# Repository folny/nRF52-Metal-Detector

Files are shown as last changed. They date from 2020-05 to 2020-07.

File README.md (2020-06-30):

# nRF52 Metal Detector

Test Video
https://www.youtube.com/watch?v=v60ftfW6UR0

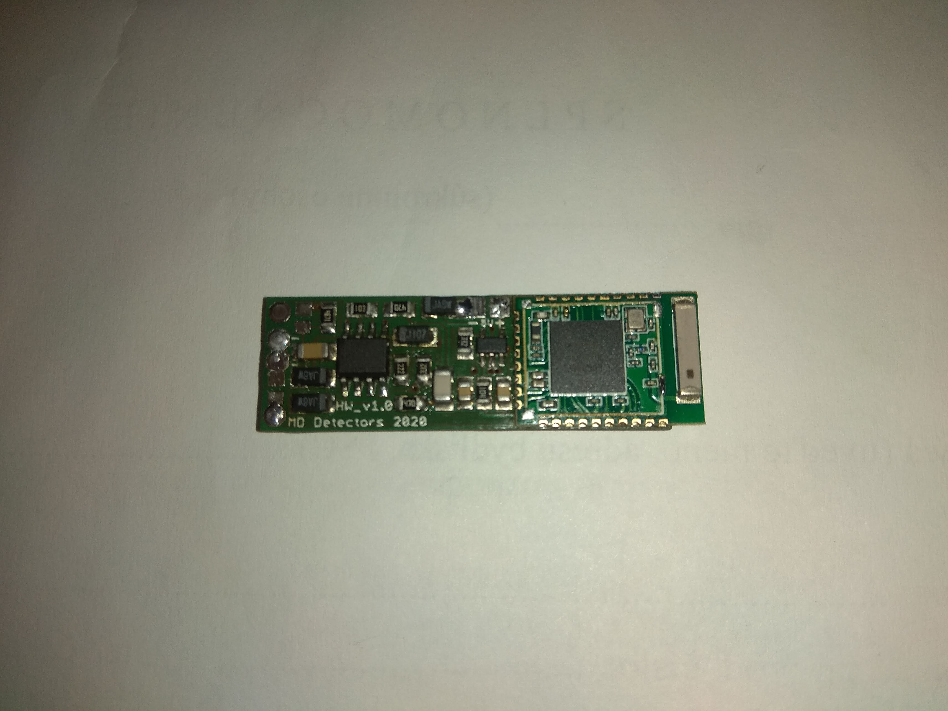
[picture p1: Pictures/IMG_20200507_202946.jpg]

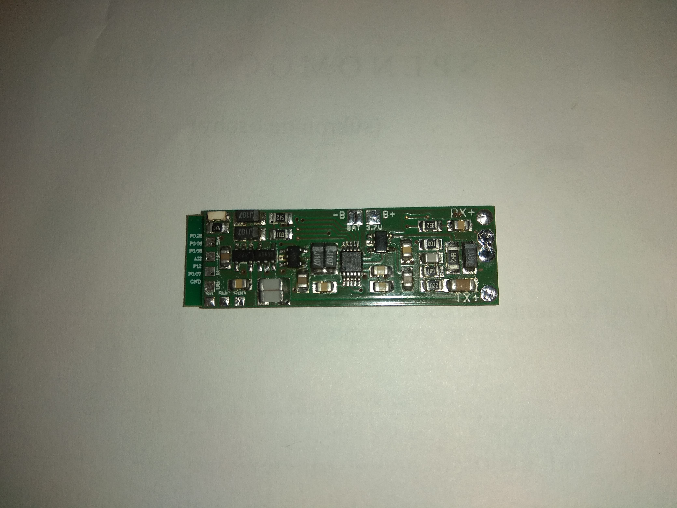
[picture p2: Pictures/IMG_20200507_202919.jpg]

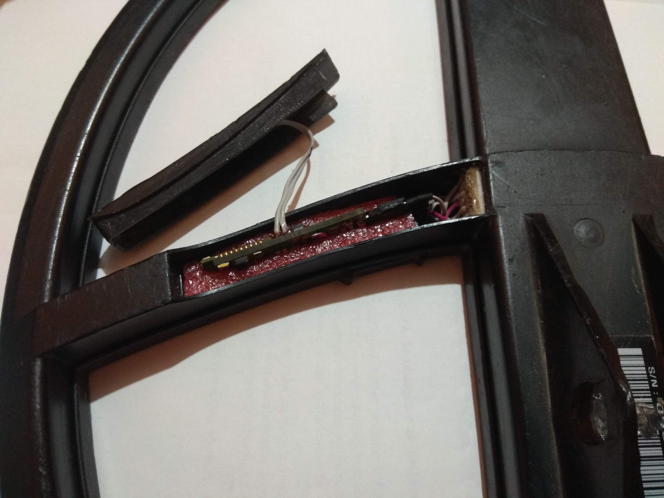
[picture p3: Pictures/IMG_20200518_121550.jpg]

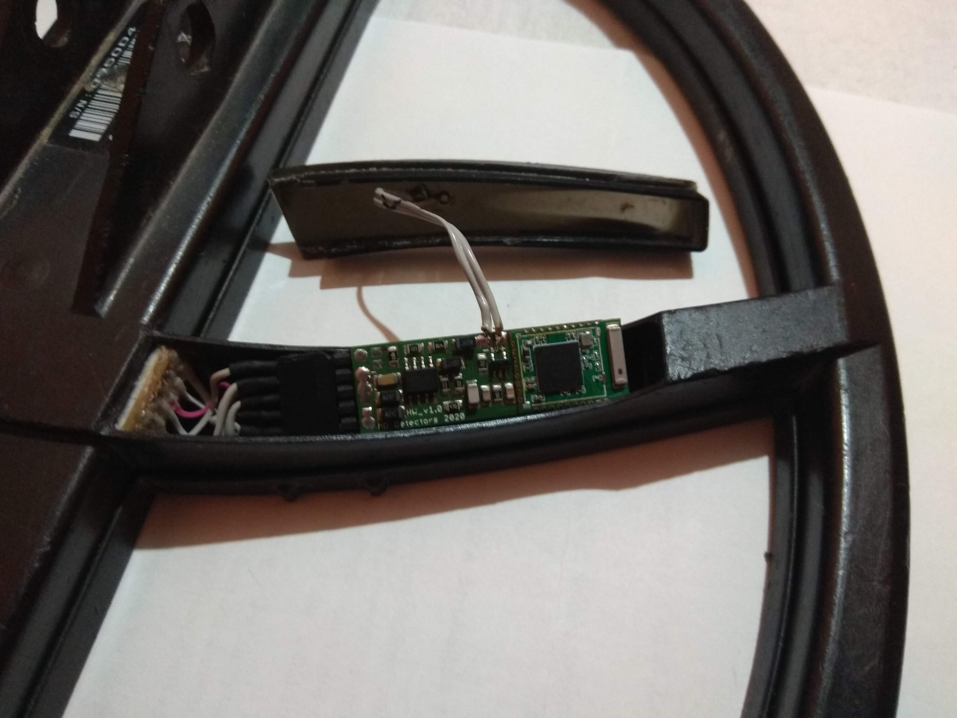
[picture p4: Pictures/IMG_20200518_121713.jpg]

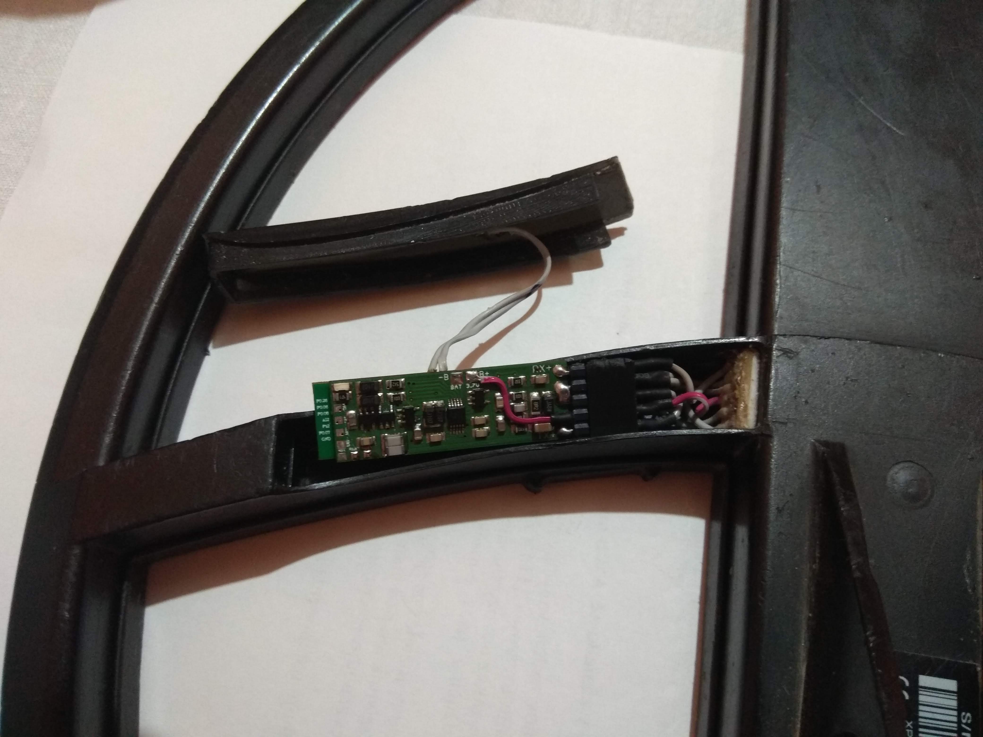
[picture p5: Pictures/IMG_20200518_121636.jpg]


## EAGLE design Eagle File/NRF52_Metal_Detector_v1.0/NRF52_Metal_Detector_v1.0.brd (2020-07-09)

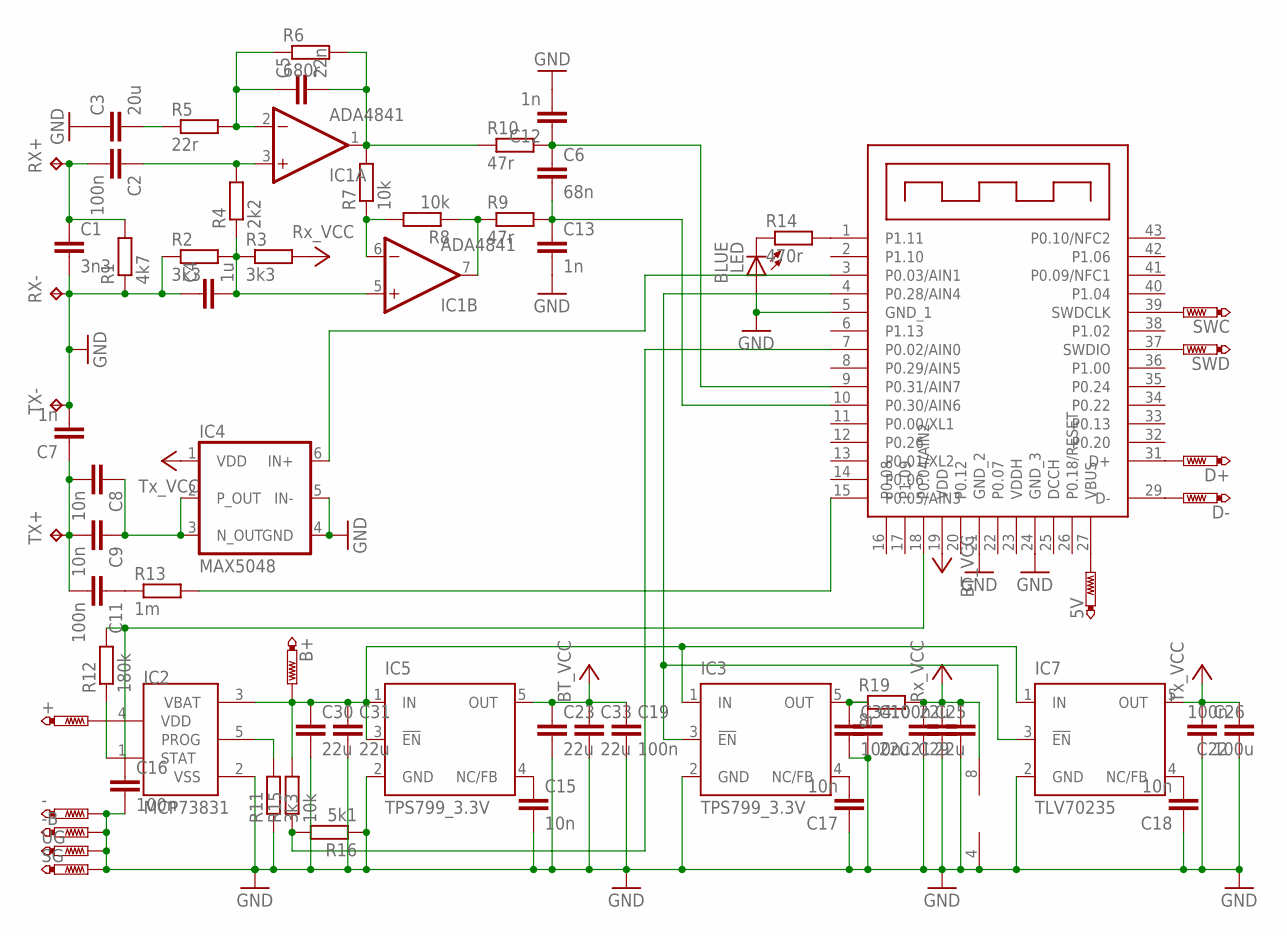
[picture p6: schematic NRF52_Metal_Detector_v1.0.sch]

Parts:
5V: PTR1TP13SQ; TP13SQ
+: PTR1TP20SQ; TP20SQ
-: PTR1TP20SQ; TP20SQ
-B: PTR1TP20SQ; TP20SQ
B+: PTR1TP20SQ; TP20SQ
C1: 3n3; C0805
C2, C11: 100n; C1206
C3: 20u; C1206
C4: 1u; C1206
C5: 22n; C0805
C6: 68n; C1206
C7, C12, C13: 1n; C0805
C8, C9: 10n; C1206
C10, C23, C25, C29, C30, C31, C33: 22u; C1206
C15, C17, C18: 10n; C0805
C16, C19, C21, C22, C34: 100n; C0805
C26: 100u; C1206
D+: PTR1TP13SQ; TP13SQ
D-: PTR1TP13SQ; TP13SQ
E73-2G4M08S1C1: E73-2G4M08S1C
IC1: ADA4841; SO08
IC2: MCP73831; SOT23-5L
IC3, IC5: TPS799_3.3V; SOT23-DBV
IC4: MAX5048; SOT23-6
IC7: TLV70235; SOT23-DBV
LED: BLUE; SML0805
R1: 4k7; R0805
R2, R3, R11: 3k3; R0805
R4: 2k2; R0805
R5: 22r; R0805
R6: 680r; R0805
R7, R8, R15: 10k; R0805
R9, R10: 47r; R0805
R12: 180k; R0805
R13: 1m; R0805
R14: 470r; R0805
R16: 5k1; R0805
R19: 8r; R1206
RX+: TPPAD1-13; P1-13
RX-: TPPAD1-13; P1-13
SG: PTR1TP13SQ; TP13SQ
SWC: PTR1TP13SQ; TP13SQ
SWD: PTR1TP13SQ; TP13SQ
TX+: TPPAD1-13; P1-13
TX-: TPPAD1-13; P1-13
UG: PTR1TP13SQ; TP13SQ

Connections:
+3V3A1: C10.1, C34.1, IC3.5 (OUT), R19.1
+3V3B: C19.1, C23.1, C33.1, E73-2G4M08S1C1.19 (VDD), IC5.5 (OUT)
+3V3T: C22.2, C26.1, IC4.1 (VDD), IC7.5 (OUT)
GND: -.TP, -B.TP, C1.2, C3.1, C4.1, C7.2, C10.2, C12.2, C13.2, C15.2, C16.2, C17.1, C18.1, C19.2, C21.1, C22.1, C23.2, C25.2, C26.2, C29.1, C30.2, C31.2, C33.2, C34.2, E73-2G4M08S1C1.5 (GND_1), E73-2G4M08S1C1.21 (GND_2), E73-2G4M08S1C1.24 (GND_3), IC1.4 (V-), IC2.2 (VSS), IC3.2 (GND), IC4.4 (GND), IC4.5 (IN-), IC5.2 (GND), IC7.2 (GND), LED.A, R1.1, R2.1, R11.1, R16.1, RX-.TP, SG.TP, TX-.TP, UG.TP
unnamed: C5.2, IC1.1 (OUT), R6.2, R7.2, R10.1
unnamed: C1.1, C2.2, R1.2, RX+.TP
unnamed: B+.TP, C30.1, C31.1, IC2.3 (VBAT), IC3.1 (IN), IC5.1 (IN), IC5.3 (!EN), IC7.1 (IN), R15.2
unnamed: C3.2, R5.1
unnamed: C5.1, IC1.2 (-IN), R5.2, R6.1
unnamed: C7.1, C8.2, C9.2, C11.2, TX+.TP
unnamed: E73-2G4M08S1C1.1 (P1.11), R14.2
unnamed: C2.1, IC1.3 (+IN), R4.2
unnamed: IC1.6 (-IN), R7.1, R8.2
unnamed: C17.2, IC3.4 (NC/FB)
unnamed: C15.1, IC5.4 (NC/FB)
unnamed: C6.2, C13.1, E73-2G4M08S1C1.10 (P0.30/AIN6), R9.2
unnamed: E73-2G4M08S1C1.39 (SWDCLK), SWC.TP
unnamed: E73-2G4M08S1C1.37 (SWDIO), SWD.TP
unnamed: +.TP, IC2.4 (VDD)
unnamed: IC2.5 (PROG), R11.2
unnamed: E73-2G4M08S1C1.4 (P0.28/AIN4), IC3.3 (!EN), IC7.3 (!EN)
unnamed: C16.1, E73-2G4M08S1C1.18 (P0.04/AIN2), R12.2
unnamed: C18.2, IC7.4 (NC/FB)
unnamed: IC2.1 (STAT), R12.1
unnamed: C8.1, C9.1, IC4.2 (P_OUT), IC4.3 (N_OUT)
unnamed: C11.1, R13.1
unnamed: E73-2G4M08S1C1.15 (P0.05/AIN3), R13.2
unnamed: LED.C, R14.1
unnamed: E73-2G4M08S1C1.7 (P0.02/AIN0), R15.1, R16.2
unnamed: C6.1, C12.1, E73-2G4M08S1C1.9 (P0.31/AIN7), R10.2
unnamed: E73-2G4M08S1C1.3 (P0.03/AIN1), IC4.6 (IN+)
unnamed: D+.TP, E73-2G4M08S1C1.31 (D+)
unnamed: D-.TP, E73-2G4M08S1C1.29 (D-)
unnamed: IC1.7 (OUT), R8.1, R9.1
unnamed: 5V.TP, E73-2G4M08S1C1.27 (VBUS)
unnamed: C4.2, IC1.5 (+IN), R2.2, R3.1, R4.1
RX_VCC: C21.2, C25.1, C29.2, IC1.8 (V+), R3.2, R19.2

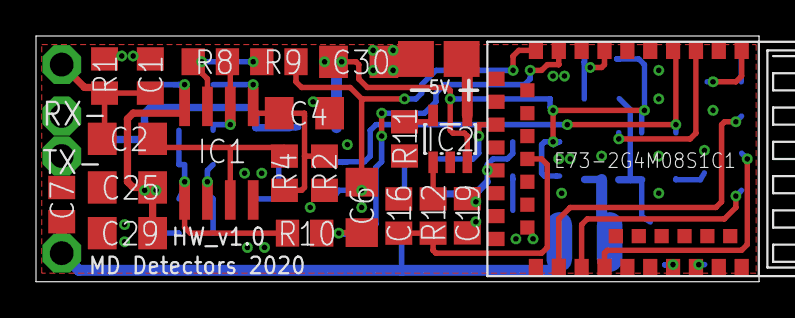
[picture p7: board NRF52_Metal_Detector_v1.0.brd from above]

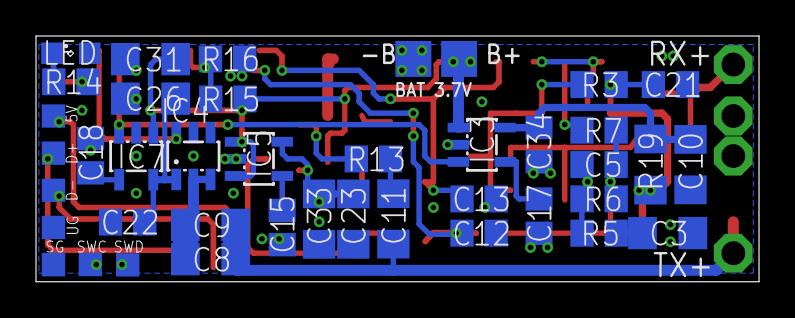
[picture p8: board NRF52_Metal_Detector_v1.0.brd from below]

Board: 2 copper layers, 40.2 x 13.7 mm, 68 parts (41 on the bottom side), 37 nets.

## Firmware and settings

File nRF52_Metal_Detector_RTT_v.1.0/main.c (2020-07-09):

#include <stdbool.h>
#include <stdint.h>
#include "sdk_common.h"
#include "nrf.h"
#include "nrf_delay.h"
#include "nrf_gpio.h"
#include "nrf_error.h"
#include "boards.h"
#include "app_util.h"
#include "nrf_log.h"
#include "nrf_log_ctrl.h"
#include "nrf_log_default_backends.h"
#include "math.h"
#include "bsp.h"
#include "app_timer.h"
#include "nrf_drv_saadc.h"
#include "nrf_drv_gpiote.h"
#include "SEGGER_RTT.h" 

//J-Link RTT Viewer Commands: i = Setup Info / 1 = Ennable, 0 = nRF Reset and Dissable Power / c = Calibrate / + = Tx Phase + / - = Tx Phase - / F = Tx Frequency + / f = Tx Frequency - (default 11.36kHz) / G = Groundbalanc + / g = Groundbalanc - / p =  Static/Dynamic Mode 

int Power = 0; 

int Frequency = 350; //Set Frequency 11.36kHz
int Phase_Set = 188; //Set TX Phase (0 - Frequency/2 Max!)
		
double GB_Set = 89.90;

int PP = 0; 

#define Tx_Coil           NRF_GPIO_PIN_MAP(0,3)
#define Power_Controll    NRF_GPIO_PIN_MAP(0,28)
#define Status_LED        NRF_GPIO_PIN_MAP(1,11)

#define GPIOTE_TASK(ch, pin, initstate) do { NRF_GPIOTE->CONFIG[ch] = ((3UL << 0) | ((pin) << 8) | (3UL << 16) | ((initstate) << 20)); } while (0)
	
#define SAMPLES 4
	
#define SAMPLES_IN_BUFFER 1

static nrf_saadc_value_t       m_buffer_pool[1][SAMPLES_IN_BUFFER];

int Calibrate = 0;
int CalibCtr  = 0;
int16_t VDI;
double X = 0.00; 
double Y = 0.00;
double X_Tmp = 0.00;
double Y_Tmp = 0.00;
double X_Filtered = 0.00;
double Y_Filtered = 0.00;	
double GEB_Ch = 0.00;	
float ADC_Data = 0.00;
int16_t ctr = -1;  
int16_t bins[SAMPLES]; 
int16_t calib[SAMPLES];
const double radiansToDegrees = 180.0/3.14;
volatile int16_t averages[SAMPLES];
volatile bool sampleReady = false;

double bin0 = 0.00;
double bin1 = 0.00;
double bin2 = 0.00;
double bin3 = 0.00;

float BandPass_a0 =  1.000000000000000000;
float BandPass_a1 = -0.000000000000000222;
float BandPass_a2 =  0.999613800419481557;
float BandPass_b0 =  0.000216661528192711;
float BandPass_b1 =  0.000000000000000000;
float BandPass_b2 = -0.000216661528192711;

float BandPass_X1, BandPass_X2, BandPass_Y1, BandPass_Y2; 

float IIR_BandPass_Filter(float x)
{
 float y, CenterTap;

 CenterTap = x * BandPass_b0 + BandPass_b1 * BandPass_X1 + BandPass_b2 * BandPass_X2;
 y = BandPass_a0 * CenterTap - BandPass_a1 * BandPass_Y1 - BandPass_a2 * BandPass_Y2;

 BandPass_X2 = BandPass_X1;
 BandPass_X1 = x;
 BandPass_Y2 = BandPass_Y1;
 BandPass_Y1 = y;

 return (float)y;
}

float XY_HPF_a0 =  1.000000000000000000;
float XY_HPF_a1 = -0.939062505817492399;
float XY_HPF_a2 =  0.000000000000000000;
float XY_HPF_b0 =  2.435352399105962910;
float XY_HPF_b1 = -2.435352399105962910;
float XY_HPF_b2 =  0.000000000000000000;

float X_HPF_X1, X_HPF_X2, X_HPF_Y1, X_HPF_Y2; 
float Y_HPF_X1, Y_HPF_X2, Y_HPF_Y1, Y_HPF_Y2; 

double IIR_X_HPF_Filter(double x){
	
 double y, CenterTap;

 CenterTap = x * XY_HPF_b0 + XY_HPF_b1 * X_HPF_X1 + XY_HPF_b2 * X_HPF_X2;
 y = XY_HPF_a0 * CenterTap - XY_HPF_a1 * X_HPF_Y1 - XY_HPF_a2 * X_HPF_Y2;

 X_HPF_X2 = X_HPF_X1;
 X_HPF_X1 = x;
 X_HPF_Y2 = X_HPF_Y1;
 X_HPF_Y1 = y;

 return (double)y;
}

double IIR_Y_HPF_Filter(double x)
{
 double y, CenterTap;

 CenterTap = x * XY_HPF_b0 + XY_HPF_b1 * Y_HPF_X1 + XY_HPF_b2 * Y_HPF_X2;
 y = XY_HPF_a0 * CenterTap - XY_HPF_a1 * Y_HPF_Y1 - XY_HPF_a2 * Y_HPF_Y2;

 Y_HPF_X2 = Y_HPF_X1;
 Y_HPF_X1 = x;
 Y_HPF_Y2 = Y_HPF_Y1;
 Y_HPF_Y1 = y;

 return (double)y;
}

float XY_LPF_a0 =  1.000000000000000000;
float XY_LPF_a1 = -0.369527377351241304;
float XY_LPF_a2 =  0.195815712655833113;
float XY_LPF_b0 =  0.206572083826147945;
float XY_LPF_b1 =  0.413144167652295891;
float XY_LPF_b2 =  0.206572083826147945;

float X_LPF_X1, X_LPF_X2, X_LPF_Y1, X_LPF_Y2; 
float Y_LPF_X1, Y_LPF_X2, Y_LPF_Y1, Y_LPF_Y2; 

double IIR_X_LPF_Filter(double x){
	
 double y, CenterTap;

 CenterTap = x * XY_LPF_b0 + XY_LPF_b1 * X_LPF_X1 + XY_LPF_b2 * X_LPF_X2;
 y = XY_LPF_a0 * CenterTap - XY_LPF_a1 * X_LPF_Y1 - XY_LPF_a2 * X_LPF_Y2;

 X_LPF_X2 = X_LPF_X1;
 X_LPF_X1 = x;
 X_LPF_Y2 = X_LPF_Y1;
 X_LPF_Y1 = y;

 return (double)y;
}

double IIR_Y_LPF_Filter(double x){
	
 double y, CenterTap;

 CenterTap = x * XY_LPF_b0 + XY_LPF_b1 * Y_LPF_X1 + XY_LPF_b2 * Y_LPF_X2;
 y = XY_LPF_a0 * CenterTap - XY_LPF_a1 * Y_LPF_Y1 - XY_LPF_a2 * Y_LPF_Y2;

 Y_LPF_X2 = Y_LPF_X1;
 Y_LPF_X1 = x;
 Y_LPF_Y2 = Y_LPF_Y1;
 Y_LPF_Y1 = y;

 return (double)y;
}

void hf_clock_enable(void)
{
    NRF_CLOCK->EVENTS_HFCLKSTARTED = 0;
    NRF_CLOCK->TASKS_HFCLKSTART = 1;
}

void hf_clock_disable(void)
{
    NRF_CLOCK->EVENTS_HFCLKSTARTED = 0;
    NRF_CLOCK->TASKS_HFCLKSTOP = 1;
}

void lf_clock_enable(void)
{
    NRF_CLOCK->LFCLKSRC            = (CLOCK_LFCLKSRC_SRC_RC << CLOCK_LFCLKSRC_SRC_Pos);
    NRF_CLOCK->EVENTS_LFCLKSTARTED = 0;
    NRF_CLOCK->TASKS_LFCLKSTART    = 1;
}

void timers_init(int frequency, int tx_phase)
{		
	  NRF_TIMER3->BITMODE                 = TIMER_BITMODE_BITMODE_16Bit << TIMER_BITMODE_BITMODE_Pos;
    NRF_TIMER3->PRESCALER               = 2;
    NRF_TIMER3->SHORTS                  = TIMER_SHORTS_COMPARE0_CLEAR_Msk << 0;
    NRF_TIMER3->MODE                    = TIMER_MODE_MODE_Timer << TIMER_MODE_MODE_Pos;
	  NRF_TIMER3->CC[0] = frequency;
	  NRF_TIMER3->CC[2] = tx_phase + 1;
    NRF_TIMER3->CC[1] = ((tx_phase + 1) + frequency/2) % frequency;   
	
    NRF_TIMER4->BITMODE                 = TIMER_BITMODE_BITMODE_16Bit << TIMER_BITMODE_BITMODE_Pos;
    NRF_TIMER4->PRESCALER               = 0;
    NRF_TIMER4->SHORTS                  = TIMER_SHORTS_COMPARE0_CLEAR_Msk << 0;
    NRF_TIMER4->MODE                    = TIMER_MODE_MODE_Timer << TIMER_MODE_MODE_Pos;
	  NRF_TIMER4->CC[0] = frequency;
 	
    NRF_TIMER4->TASKS_STOP = 1;		
    NRF_TIMER3->TASKS_STOP = 1;              
}

void saadc_callback(nrf_drv_saadc_evt_t const * p_event)
{
    if(p_event->type == NRF_DRV_SAADC_EVT_DONE){
		
    ctr++;
			
    nrf_drv_saadc_buffer_convert(p_event->data.done.p_buffer, SAMPLES_IN_BUFFER); 
		
	  ADC_Data = p_event->data.done.p_buffer[0];
    bins[ctr] = (double)IIR_BandPass_Filter(ADC_Data);
	
 if(ctr == SAMPLES -1){

 if(Calibrate == 1){	
		calib[0] = bins[0];
		calib[1] = bins[1];
		calib[2] = bins[2];
		calib[3] = bins[3];
	  Calibrate = 0;
		}else{
	  if (!sampleReady){
    bin0 = ((bins[0]-calib[0]) + ((bins[1]-calib[1]) - (bins[3]-calib[3])));
    bin1 = ((bins[1]-calib[1]) + ((bins[0]-calib[0]) + (bins[2]-calib[2])));
    bin2 = ((bins[2]-calib[2]) + ((bins[1]-calib[1]) + (bins[3]-calib[3])));
    bin3 = ((bins[3]-calib[3]) + ((bins[2]-calib[2]) - (bins[0]-calib[0]))); 
	  sampleReady = true;
    }
    }
		ctr = -1;
   } 			
  }
}

void rx_saadc_init(void) {
 				
	  nrf_drv_saadc_config_t rx_saadc_config;
    nrf_saadc_channel_config_t rx_channel_config;
	
    //Rx Configure SAADC
    rx_saadc_config.low_power_mode = false;                                                    
    rx_saadc_config.resolution = NRF_SAADC_RESOLUTION_14BIT;                                
	  rx_saadc_config.oversample = NRF_SAADC_OVERSAMPLE_4X; 
    rx_saadc_config.interrupt_priority = APP_IRQ_PRIORITY_HIGH;                              
	
    nrf_drv_saadc_init(&rx_saadc_config,saadc_callback);                       
		
    rx_channel_config.reference = NRF_SAADC_REFERENCE_INTERNAL;                              
    rx_channel_config.gain = NRF_SAADC_GAIN4;  
    rx_channel_config.burst = NRF_SAADC_BURST_ENABLED;		
    rx_channel_config.acq_time = NRF_SAADC_ACQTIME_3US;                                     
    rx_channel_config.mode = NRF_SAADC_MODE_DIFFERENTIAL;                                    
    rx_channel_config.pin_p = (nrf_saadc_input_t)NRF_SAADC_INPUT_AIN7;                                         
    rx_channel_config.pin_n = (nrf_saadc_input_t)NRF_SAADC_INPUT_AIN6;                                      
    rx_channel_config.resistor_p = NRF_SAADC_RESISTOR_DISABLED;                               
    rx_channel_config.resistor_n = NRF_SAADC_RESISTOR_DISABLED;		
	 
    NRF_SAADC->CH[0].CONFIG |= 0x01000000;                                   
		
		nrf_drv_saadc_channel_init(0, &rx_channel_config);				
	  nrf_drv_saadc_buffer_convert(m_buffer_pool[0],SAMPLES_IN_BUFFER);
}

void gpiote_init(void){
	
    GPIOTE_TASK(1, Tx_Coil, 0);
	
	  NRF_PPI->CH[1].EEP =(uint32_t)& NRF_TIMER3->EVENTS_COMPARE[1];
    NRF_PPI->CH[1].TEP = (uint32_t)&NRF_GPIOTE->TASKS_SET[1];
    NRF_PPI->CHENSET = (1UL << 1);
    NRF_PPI->CH[2].EEP = (uint32_t)&NRF_TIMER3->EVENTS_COMPARE[2];
    NRF_PPI->CH[2].TEP = (uint32_t)&NRF_GPIOTE->TASKS_CLR[1];
    NRF_PPI->CHENSET = (1UL << 2);
	
	  NRF_PPI->CH[0].EEP = (uint32_t)&NRF_TIMER4->EVENTS_COMPARE[0];
    NRF_PPI->CH[0].TEP = (uint32_t)&NRF_SAADC->TASKS_SAMPLE;
    NRF_PPI->CHENSET = (1UL << 0);
}

int main(void)
{
	  NRF_POWER->DCDCEN = true;
	
	  lf_clock_enable();
	
		NRF_LOG_INIT(NULL);
    NRF_LOG_DEFAULT_BACKENDS_INIT();
	
	  nrf_gpio_cfg_output(Tx_Coil);
	  nrf_gpio_cfg_output(Power_Controll);
	  nrf_gpio_pin_write(Power_Controll,0);
	  nrf_gpio_cfg_output(Status_LED);
	  nrf_gpio_pin_write(Status_LED,0);
	
		app_timer_init();			
	  bsp_init(BSP_INIT_LEDS, NULL);
	
	  bsp_indication_set(BSP_INDICATE_ADVERTISING); 
		
	  SEGGER_RTT_WriteString(0,"Config Ready... Power Disabled\n");
		nrf_delay_ms(200);

while(1){  	
		
    char RTT_Data = 0;

	  RTT_Data = SEGGER_RTT_GetKey(); 
	
	  if(RTT_Data == 'i'){
    SEGGER_RTT_printf(0,"Frequency:%d Tx Phase:%d GB:%d \n",(int)Frequency,(int)Phase_Set,(int)GB_Set);
		nrf_delay_ms(500);
	  }

    if(RTT_Data == '1'){
		hf_clock_enable();
    nrf_gpio_pin_write(Power_Controll,1);
	  timers_init(Frequency,Phase_Set);
	  NRF_TIMER4->TASKS_START = 1;		
    NRF_TIMER3->TASKS_START = 1;
	  rx_saadc_init(); 
		gpiote_init();				
		Power = 1;
	  bsp_indication_set(BSP_INDICATE_ADVERTISING_WHITELIST);			
    SEGGER_RTT_WriteString(0,"Config Ready... Power Enabled\n");			
	  nrf_delay_ms(200);
	  }

    if(RTT_Data == '0'){
    NVIC_SystemReset();
	  }	
			
	  if(RTT_Data == 'c'){
	  SEGGER_RTT_WriteString(0,"Calibrate\n");
	  Calibrate = 1;
	  }
	
    if(RTT_Data == '+'){
   	SEGGER_RTT_printf(0,"TX Phase:%d\n",(int)Phase_Set);
	  Phase_Set++;
    NRF_TIMER3->CC[2] = Phase_Set + 1;
    NRF_TIMER3->CC[1] = ((Phase_Set + 1) + Frequency/2) % Frequency;
	  CalibCtr = 0;
	  }
	
    if(RTT_Data == '-'){
	  SEGGER_RTT_printf(0,"TX Phase:%d\n",(int)Phase_Set);
	  Phase_Set--;
	  NRF_TIMER3->CC[2] = Phase_Set + 1;
    NRF_TIMER3->CC[1] = ((Phase_Set + 1) + Frequency/2) % Frequency;
	  CalibCtr = 0;
	  }
	
	  if(RTT_Data == 'F'){
	  SEGGER_RTT_printf(0,"Frequency:%d\n",(int)Frequency);
	  Frequency++;
    NRF_TIMER3->CC[0] = Frequency;
    NRF_TIMER3->CC[2] = Phase_Set + 1;
    NRF_TIMER3->CC[1] = ((Phase_Set + 1) + Frequency/2) % Frequency;
  	NRF_TIMER4->CC[0] = Frequency;
  	CalibCtr = 0;
	  }
	
    if(RTT_Data == 'f'){
	  SEGGER_RTT_printf(0,"Frequency:%d\n",(int)Frequency);
	  Frequency--;
    NRF_TIMER3->CC[0] = Frequency;
    NRF_TIMER3->CC[2] = Phase_Set + 1;
    NRF_TIMER3->CC[1] = ((Phase_Set + 1) + Frequency/2) % Frequency;
   	NRF_TIMER4->CC[0] = Frequency;
  	CalibCtr = 0;
  	}
	
    if(RTT_Data == 'G'){
   	GB_Set += 0.1;
    SEGGER_RTT_printf(0,"GB:%d\n",(int)GB_Set);
	  }
	
    if(RTT_Data == 'g'){
	  GB_Set -= 0.1;
    SEGGER_RTT_printf(0,"GB:%d\n",(int)GB_Set);
	  }
	
	  if(RTT_Data == 'p'){
    if(PP == 1){
	  PP = 0;
    SEGGER_RTT_WriteString(0,"Dynamic Mode\n");
	  }else{
   	PP = 1;
    SEGGER_RTT_WriteString(0,"Static Mode\n");
    Calibrate = 1;
	}
}
	  if(Power == 1){
			
	  if(CalibCtr++ == 20){
		Calibrate = 1;	
		}
				
	  if(PP == 1){
	  X = (bin0 + bin2);
	  Y = (bin1 + bin3);
		}else{
	  X = IIR_X_HPF_Filter(bin0 + bin2);
	  Y = IIR_Y_HPF_Filter(bin1 + bin3);	
		}

	  X_Filtered = IIR_X_LPF_Filter(X);
    Y_Filtered = IIR_Y_LPF_Filter(Y);
	  sampleReady = false;	
				
	  GEB_Ch = (X_Filtered - (0.9-((double)GB_Set/100)) * Y_Filtered);	
		
    if(GEB_Ch >= 5){
	  VDI = (atan2(Y_Filtered - Y_Tmp,X_Filtered - X_Tmp) * radiansToDegrees);	 
	  if(GEB_Ch >= 999){
	  SEGGER_RTT_printf(0,"Amp:%d VDI:%d\n",1000,(int)VDI);
		}else{
	  SEGGER_RTT_printf(0,"Amp:%d VDI:%d\n",(int)GEB_Ch,(int)VDI);
		}
		if(GEB_Ch >= 999){
	  SEGGER_RTT_printf(0,"Amp:%d VDI:%d\n",1000,(int)VDI);
		}else{
	  SEGGER_RTT_printf(0,"Amp:%d VDI:%d\n",(int)GEB_Ch,(int)VDI);	
		}
		}else{
    X_Tmp = X_Filtered;
    Y_Tmp = Y_Filtered;
		if(GEB_Ch <= -1){
    SEGGER_RTT_printf(0,"Amp:%d \n",0);
		}else{
	  SEGGER_RTT_printf(0,"Amp:%d \n",(int)GEB_Ch);	
		}
	 }
	}
  nrf_delay_ms(16);
 }
}

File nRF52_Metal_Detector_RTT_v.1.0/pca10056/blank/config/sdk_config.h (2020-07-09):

/**
 * Copyright (c) 2017 - 2019, Nordic Semiconductor ASA
 *
 * All rights reserved.
 *
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
 * 3. Neither the name of Nordic Semiconductor ASA nor the names of its
 *    contributors may be used to endorse or promote products derived from this
 *    software without specific prior written permission.
 *
 * 4. This software, with or without modification, must only be used with a
 *    Nordic Semiconductor ASA integrated circuit.
 *
 * 5. Any software provided in binary form under this license must not be reverse
 *    engineered, decompiled, modified and/or disassembled.
 *
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
 */



#ifndef SDK_CONFIG_H
#define SDK_CONFIG_H
// <<< Use Configuration Wizard in Context Menu >>>\n
#ifdef USE_APP_CONFIG
#include "app_config.h"
#endif
// <h> nRF_Drivers 

//<e> NRFX_SPIM_ENABLED - nrfx_spim - SPIM peripheral driver
//==========================================================
#ifndef NRFX_SPIM_ENABLED
#define NRFX_SPIM_ENABLED 0
#endif
// <q> NRFX_SPIM0_ENABLED  - Enable SPIM0 instance
 

#ifndef NRFX_SPIM0_ENABLED
#define NRFX_SPIM0_ENABLED 0
#endif

// <q> NRFX_SPIM1_ENABLED  - Enable SPIM1 instance
 

#ifndef NRFX_SPIM1_ENABLED
#define NRFX_SPIM1_ENABLED 0
#endif

// <q> NRFX_SPIM2_ENABLED  - Enable SPIM2 instance
 

#ifndef NRFX_SPIM2_ENABLED
#define NRFX_SPIM2_ENABLED 0
#endif

// <q> NRFX_SPIM3_ENABLED  - Enable SPIM3 instance
 

#ifndef NRFX_SPIM3_ENABLED
#define NRFX_SPIM3_ENABLED 0
#endif

// <q> NRFX_SPIM_EXTENDED_ENABLED  - Enable extended SPIM features
 

#ifndef NRFX_SPIM_EXTENDED_ENABLED
#define NRFX_SPIM_EXTENDED_ENABLED 0
#endif

// <o> NRFX_SPIM_MISO_PULL_CFG  - MISO pin pull configuration.
 
// <0=> NRF_GPIO_PIN_NOPULL 
// <1=> NRF_GPIO_PIN_PULLDOWN 
// <3=> NRF_GPIO_PIN_PULLUP 

#ifndef NRFX_SPIM_MISO_PULL_CFG
#define NRFX_SPIM_MISO_PULL_CFG 0
#endif

// <o> NRFX_SPIM_DEFAULT_CONFIG_IRQ_PRIORITY  - Interrupt priority
 
// <0=> 0 (highest) 
// <1=> 1 
// <2=> 2 
// <3=> 3 
// <4=> 4 
// <5=> 5 
// <6=> 6 
// <7=> 7 

#ifndef NRFX_SPIM_DEFAULT_CONFIG_IRQ_PRIORITY
#define NRFX_SPIM_DEFAULT_CONFIG_IRQ_PRIORITY 6
#endif

// <e> NRFX_PWM_ENABLED - nrfx_pwm - PWM peripheral driver
//==========================================================
#ifndef NRFX_PWM_ENABLED
#define NRFX_PWM_ENABLED 1
#endif
// <q> NRFX_PWM0_ENABLED  - Enable PWM0 instance
 

#ifndef NRFX_PWM0_ENABLED
#define NRFX_PWM0_ENABLED 0
#endif

// <q> NRFX_PWM1_ENABLED  - Enable PWM1 instance
 

#ifndef NRFX_PWM1_ENABLED
#define NRFX_PWM1_ENABLED 0
#endif

// <q> NRFX_PWM2_ENABLED  - Enable PWM2 instance
 

#ifndef NRFX_PWM2_ENABLED
#define NRFX_PWM2_ENABLED 0
#endif

// <o> NRFX_PWM_DEFAULT_CONFIG_OUT0_PIN - Out0 pin  <0-31> 


#ifndef NRFX_PWM_DEFAULT_CONFIG_OUT0_PIN
#define NRFX_PWM_DEFAULT_CONFIG_OUT0_PIN 0
#endif

// <o> NRFX_PWM_DEFAULT_CONFIG_OUT1_PIN - Out1 pin  <0-31> 


#ifndef NRFX_PWM_DEFAULT_CONFIG_OUT1_PIN
#define NRFX_PWM_DEFAULT_CONFIG_OUT1_PIN 0
#endif

// <o> NRFX_PWM_DEFAULT_CONFIG_OUT2_PIN - Out2 pin  <0-31> 


#ifndef NRFX_PWM_DEFAULT_CONFIG_OUT2_PIN
#define NRFX_PWM_DEFAULT_CONFIG_OUT2_PIN 0
#endif

// <o> NRFX_PWM_DEFAULT_CONFIG_OUT3_PIN - Out3 pin  <0-31> 


#ifndef NRFX_PWM_DEFAULT_CONFIG_OUT3_PIN
#define NRFX_PWM_DEFAULT_CONFIG_OUT3_PIN 0
#endif

// <o> NRFX_PWM_DEFAULT_CONFIG_BASE_CLOCK  - Base clock
 
// <0=> 16 MHz 
// <1=> 8 MHz 
// <2=> 4 MHz 
// <3=> 2 MHz 
// <4=> 1 MHz 
// <5=> 500 kHz 
// <6=> 250 kHz 
// <7=> 125 kHz 

#ifndef NRFX_PWM_DEFAULT_CONFIG_BASE_CLOCK
#define NRFX_PWM_DEFAULT_CONFIG_BASE_CLOCK 0
#endif

// <o> NRFX_PWM_DEFAULT_CONFIG_COUNT_MODE  - Count mode
 
// <0=> Up 
// <1=> Up and Down 

#ifndef NRFX_PWM_DEFAULT_CONFIG_COUNT_MODE
#define NRFX_PWM_DEFAULT_CONFIG_COUNT_MODE 0
#endif

// <o> NRFX_PWM_DEFAULT_CONFIG_TOP_VALUE - Top value 
#ifndef NRFX_PWM_DEFAULT_CONFIG_TOP_VALUE
#define NRFX_PWM_DEFAULT_CONFIG_TOP_VALUE 1000
#endif

// <o> NRFX_PWM_DEFAULT_CONFIG_LOAD_MODE  - Load mode
 
// <0=> Common 
// <1=> Grouped 
// <2=> Individual 
// <3=> Waveform 

#ifndef NRFX_PWM_DEFAULT_CONFIG_LOAD_MODE
#define NRFX_PWM_DEFAULT_CONFIG_LOAD_MODE 0
#endif

// <o> NRFX_PWM_DEFAULT_CONFIG_STEP_MODE  - Step mode
 
// <0=> Auto 
// <1=> Triggered 

#ifndef NRFX_PWM_DEFAULT_CONFIG_STEP_MODE
#define NRFX_PWM_DEFAULT_CONFIG_STEP_MODE 0
#endif

// <o> NRFX_PWM_DEFAULT_CONFIG_IRQ_PRIORITY  - Interrupt priority
 
// <0=> 0 (highest) 
// <1=> 1 
// <2=> 2 
// <3=> 3 
// <4=> 4 
// <5=> 5 
// <6=> 6 
// <7=> 7 

#ifndef NRFX_PWM_DEFAULT_CONFIG_IRQ_PRIORITY
#define NRFX_PWM_DEFAULT_CONFIG_IRQ_PRIORITY 6
#endif

// <e> PWM_ENABLED - nrf_drv_pwm - PWM peripheral driver - legacy layer
//==========================================================
#ifndef PWM_ENABLED
#define PWM_ENABLED 1
#endif
// <o> PWM_DEFAULT_CONFIG_OUT0_PIN - Out0 pin  <0-31> 


#ifndef PWM_DEFAULT_CONFIG_OUT0_PIN
#define PWM_DEFAULT_CONFIG_OUT0_PIN 0
#endif

// <o> PWM_DEFAULT_CONFIG_OUT1_PIN - Out1 pin  <0-31> 


#ifndef PWM_DEFAULT_CONFIG_OUT1_PIN
#define PWM_DEFAULT_CONFIG_OUT1_PIN 0
#endif
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

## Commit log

2020-07-09 Add Eagle File
    [NRF52_Metal_Detector_v1.0.brd, NRF52_Metal_Detector_v1.0.sch]
2020-07-09 Update Eagle Files
    [NRF52_Metal_Detector_v1.0.brd, NRF52_Metal_Detector_v1.0.sch]
